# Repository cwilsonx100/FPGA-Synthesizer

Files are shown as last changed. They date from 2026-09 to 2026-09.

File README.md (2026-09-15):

<h3 align="center">FPGA Synthesizer</h3>

  <p align="center">
    A musical synthesizer that runs on an Artix-7 Cmod A7-35T
    <br />
    <br />

  </p>
</div>

## Overview

Includes 10-Voice Polyphony with Filters, Detune Oscillators, Phase Modulation, and ADSR. All with Variable controls.

Includes a Mono Sequencer with in-key randomization options.

Waveforms and Timing decisions are generated on the FPGA, while the User Interface and Variable controls are delegated to the PI.

A Modular System that supports up to 64 Potentiometers for Variable controls.

Connects to any MIDI keyboard through a standard MIDI DIN cable.

### Built With

* [][Verilog-url]
* [][Kicad-url]
* [][Vivado-url]
* [][Python-url]
* [][MIDI-url]
* [][pi-url]
* [][FastAPI-url]

### Main Hardware

Artix-7 Cmod A7-35T

Adafruit I2S Stereo Decoder - UDA1334A Breakout

Raspberry Pi 4 Model B

Full Hardware list is in the BOM

## Functional overview

### Artix-7 Cmod A7-35T FPGA

The FPGA generates the base waveforms and timing sequences through MMCM.

More complex waveforms use wavetables with a saw wave as their reference.

Note and MIDI Values are stored as LUTs.

Filters and effects then alter the waveform with predictable algorithms and formulas.

The FPGA then parses MIDI data to send the waveform to a DAC.

### Raspberry Pi 4 Model B

The Pi handles everything on the User end.

The User Interface allows for a modular system of up to 64 potentiometers, but also allows for a fully digital system with no analog components.

Allows for a fully customizable sequencer system with in-key randomizers and timing variables.

Communicates variable changes and timing to the FPGA through SPI.

### PCB

Includes Gerber Files and a full BOM.

The prototype was first breadboarded and then designed in KiCad.

Schematic

PCB

3dBoard

<!-- CONTACT -->
## Contact

Connor Wilson - Cwilsonx100@gmail.com

<!-- MARKDOWN LINKS & IMAGES -->
[Verilog.com]: https://img.shields.io/badge/Hardware-Verilog-blue
[Verilog-url]: https://www.verilog.com/
[Kicad.org]: https://img.shields.io/badge/Hardware-KiCad-blue
[Kicad-url]: https://www.kicad.org/
[AMD.com]: https://img.shields.io/badge/EDA-Vivado-blue
[Vivado-url]: https://www.amd.com/en/products/software/adaptive-socs-and-fpgas/vivado.html
[Python.org]: https://img.shields.io/badge/Python-3776AB?logo=python&logoColor=fff
[Python-url]: https://www.python.org/
[MIDI.org]: https://img.shields.io/badge/-MIDI-000000?style=for-the-badge&logo=midi&logoColor=white
[MIDI-url]: https://midi.org/
[raspberrypi.com]: https://img.shields.io/badge/-RaspberryPi-C51A4A?style=for-the-badge&logo=Raspberry-Pi
[PI-url]: https://www.raspberrypi.com/
[fastapi.tiangolo.com]: https://img.shields.io/badge/FastAPI-005571?style=for-the-badge&logo=fastapi
[FastAPI-url]: https://fastapi.tiangolo.com/

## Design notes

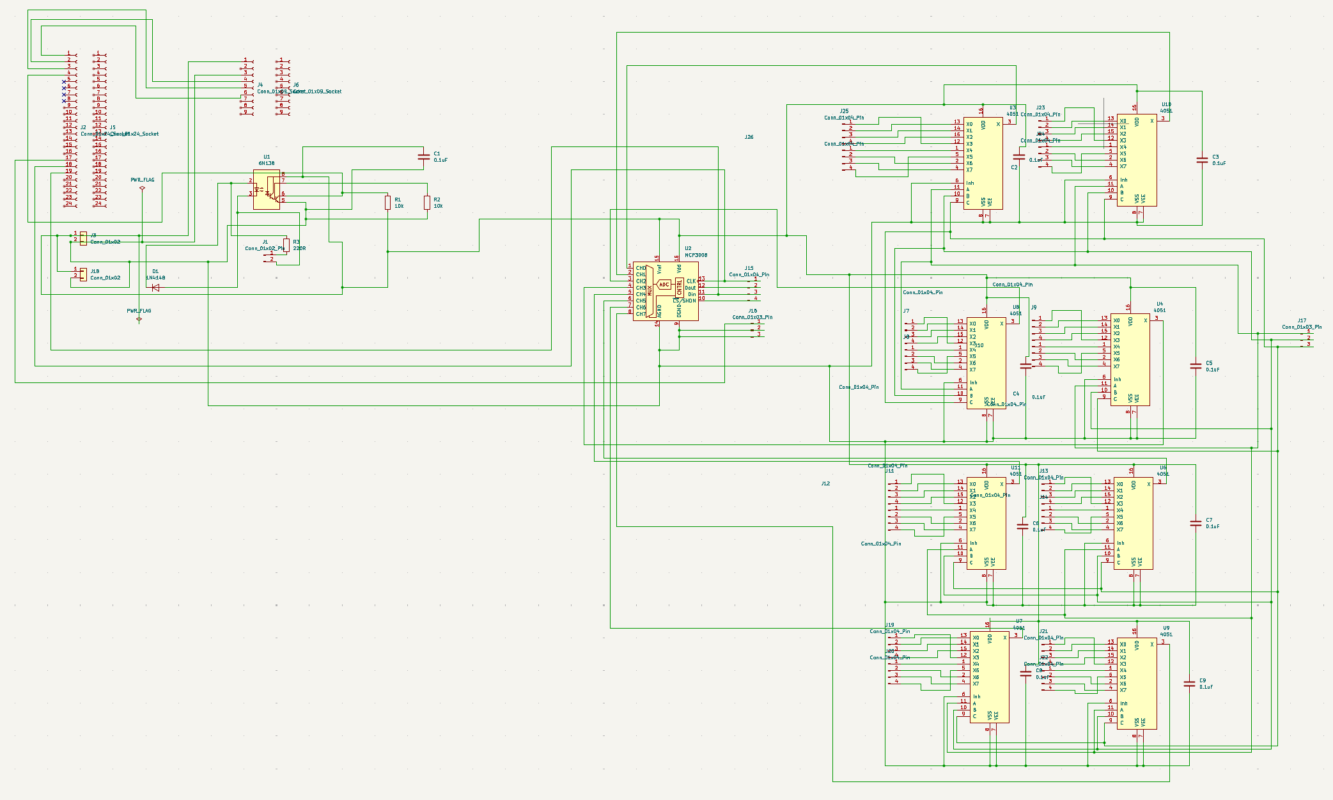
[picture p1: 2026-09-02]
Images/Schematic.png

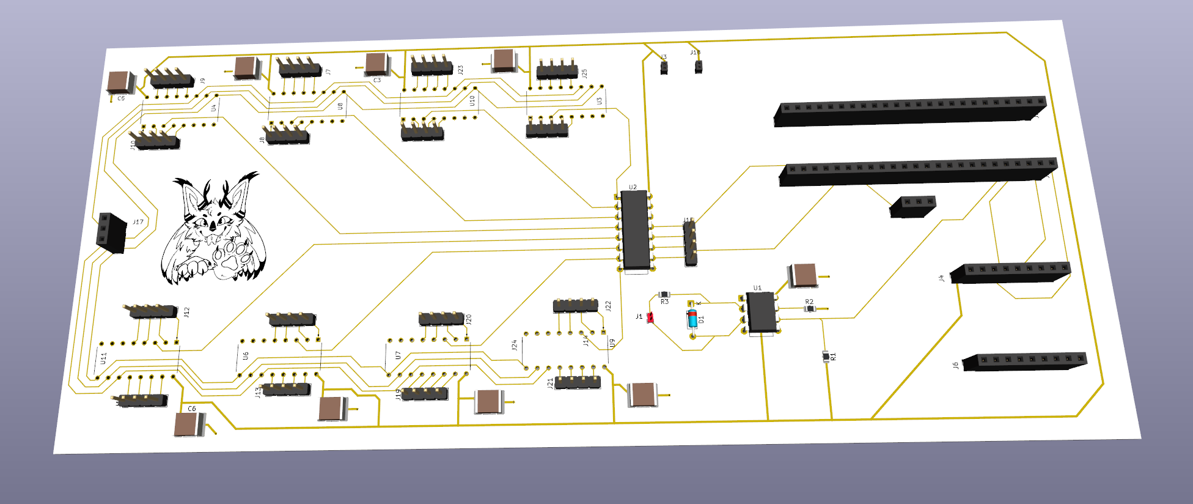
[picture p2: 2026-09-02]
Images/3dBoard.png

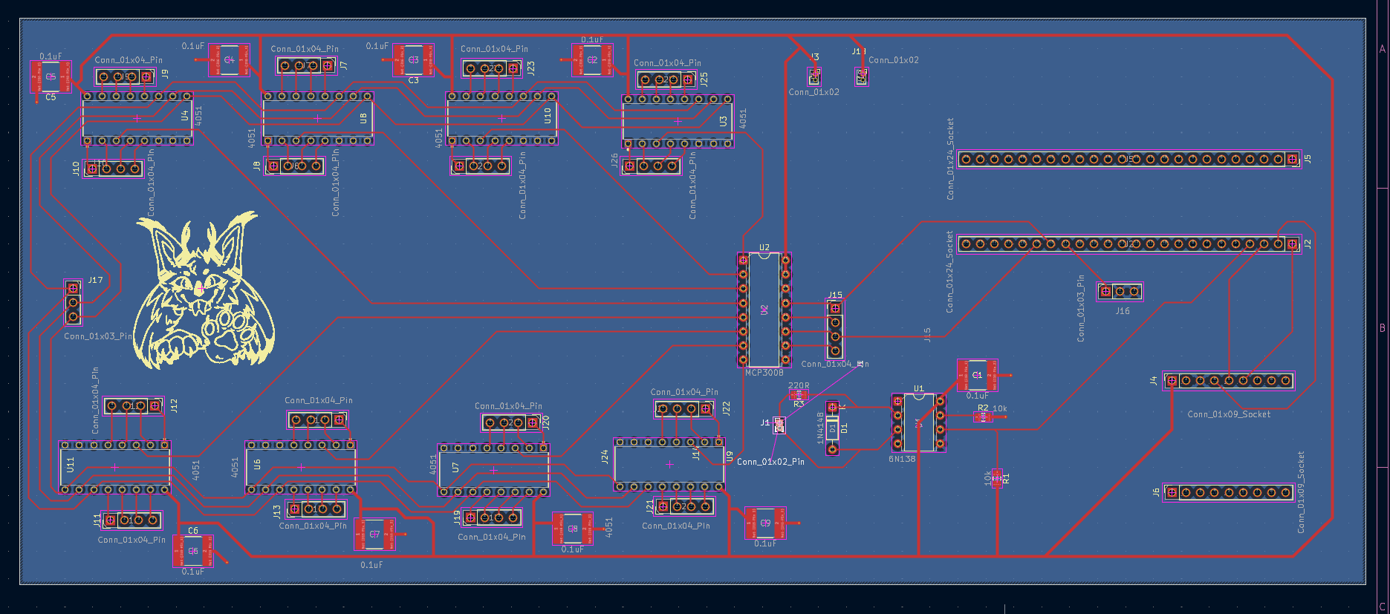
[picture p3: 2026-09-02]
Images/PCB.png

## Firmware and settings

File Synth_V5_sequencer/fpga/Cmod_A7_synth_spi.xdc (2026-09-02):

## Cmod A7 configuration voltage settings
set_property CFGBVS VCCO [current_design]
set_property CONFIG_VOLTAGE 3.3 [current_design]

## 12 MHz board clock (onboard oscillator)
set_property -dict { PACKAGE_PIN L17 IOSTANDARD LVCMOS33 } [get_ports { clk }]
## NOTE: do NOT add create_clock here. The clk_wiz_0 IP already constrains the
## 12 MHz input clock (its in-context XDC). A second create_clock on this pin
## causes CRITICAL WARNING [Constraints 18-1056] "completely overrides clock",
## which corrupts audio-clock timing and makes the SPI slave unreliable.

## Onboard LED
set_property -dict { PACKAGE_PIN A17 IOSTANDARD LVCMOS33 } [get_ports { led0 }]

## I2S to UDA1334A  (DIP pins 1/2/3 = pio1/2/3)
set_property -dict { PACKAGE_PIN M3  IOSTANDARD LVCMOS33 } [get_ports { i2s_bclk }]
set_property -dict { PACKAGE_PIN L3  IOSTANDARD LVCMOS33 } [get_ports { i2s_lrclk }]
set_property -dict { PACKAGE_PIN A16 IOSTANDARD LVCMOS33 } [get_ports { i2s_sdin }]

## MIDI input  (DIP pin 4 = pio4, notes only)
set_property -dict { PACKAGE_PIN K3  IOSTANDARD LVCMOS33 } [get_ports { midi_rx }]

## ======================================================================
## SPI from Raspberry Pi (Pi = master, FPGA = slave)
## Placed on the high-numbered header pins, clear of audio/MIDI (pins 1-4)
## and the analog pins (15/16). Package pins verified against Digilent's
## Cmod A7 Master XDC (DIP pin N == pio[N]).
##
##   Signal     DIP pin (silkscreen)   pio     Package pin
##   spi_cs_n         17               pio17       M1
##   spi_sclk        18               pio18       N3
##   spi_mosi        19               pio19       P3
## ======================================================================
set_property -dict { PACKAGE_PIN M1  IOSTANDARD LVCMOS33 } [get_ports { spi_cs_n }]
set_property -dict { PACKAGE_PIN N3  IOSTANDARD LVCMOS33 } [get_ports { spi_sclk }]
set_property -dict { PACKAGE_PIN P3  IOSTANDARD LVCMOS33 } [get_ports { spi_mosi }]

## SPI is slow/async relative to clk_audio; synchronizers handle crossing.
## Mark the SPI inputs as false paths to avoid meaningless timing errors.
set_false_path -from [get_ports { spi_sclk spi_mosi spi_cs_n }]

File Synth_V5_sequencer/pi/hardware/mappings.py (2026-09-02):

"""
Register map, muxed-pot layout, and scaling. Single source of truth shared
conceptually with the FPGA Param_regfile.v.

Hardware: the PCB has 8x CD74HC4051 mux positions, one per MCP3008 channel,
all sharing select lines (index 0..7). Populate as few or as many as you like:
set ENABLED_MUX_CHANNELS to just the ADC channels whose mux is actually
soldered down. Unpopulated channels are skipped entirely, which also keeps the
scan fast.

A pot is addressed by (adc_channel, mux_index):

    slot = adc_channel * 8 + mux_index      (0..63)

PCB mux -> ADC channel map (from the KiCad netlist):
    U3 -> CH0    U10 -> CH1   U8  -> CH2   U4 -> CH3
    U11-> CH4    U6  -> CH5   U7  -> CH6   U9 -> CH7
"""
import math

FS = 48000  # audio sample rate (must match FPGA)

# ---- register addresses (must match Param_regfile.v) ----
REG = {
    "attack":        0x00,
    "decay":         0x01,
    "sustain":       0x02,
    "release":       0x03,
    "pulse_width":   0x04,
    "detune":        0x05,
    "filter_f":      0x06,
    "volume":        0x07,
    "waveform":      0x08,
    "voice_mask":    0x09,
    "mute":          0x0A,
    "filter_bypass": 0x0B,
    "osc_b":         0x0C,
    "filter_q":      0x0D,
    "filter_type":   0x0E,
}

# ---- WHICH MUXES ARE POPULATED -------------------------------------------
# The board has all 8 positions; list only the ADC channels you actually
# populated. Add a channel here when you solder that mux down - nothing else
# needs to change. Example: [0] for one mux, [0,1,2] for three, range(8) for all.
ENABLED_MUX_CHANNELS = list(range(8))

# PCB reference designator per ADC channel (for the GUI / documentation only)
MUX_REFDES = {0: "U3", 1: "U10", 2: "U8", 3: "U4",
              4: "U11", 5: "U6", 6: "U7", 7: "U9"}

MUX_ADC_CHANNELS = list(ENABLED_MUX_CHANNELS)   # scanned channels
MUX_COUNT = len(MUX_ADC_CHANNELS)
POT_COUNT = MUX_COUNT * 8
MAX_POT_COUNT = 64                              # if all 8 muxes populated


def slot_to_addr(adc_channel, mux_index):
    return adc_channel * 8 + mux_index


# ---- special scaling for the two filter knobs ----
def cutoff_to_f(v01):
    """Pot 0..1 -> SVF f coefficient (Q14). Log-mapped cutoff 30 Hz..7500 Hz.
       f = sin(pi*Fc/Fs) (calibrated to this filter)."""
    fmin, fmax = 30.0, 7500.0
    fc = fmin * (fmax / fmin) ** v01           # exponential/log sweep
    f_real = math.sin(math.pi * fc / FS)
    f_real = max(0.0, min(0.90, f_real))        # hard cap < 1.0 for SVF stability
    return int(round(f_real * 16384))          # Q14 (<= ~14746, safely < 16384)


def resonance_to_q(v01):
    """Pot 0..1 -> SVF q coefficient (Q14). q = 1/Q.
       Low pot = damped (q~1.4), high pot = very resonant (q small)."""
    qmin_res, qmax_res = 0.05, 1.5             # q_real range (small = resonant)
    # invert so clockwise = more resonance (smaller q)
    q_real = qmax_res + (qmin_res - qmax_res) * v01
    q_real = max(0.02, min(3.99, q_real))
    return int(round(q_real * 16384))          # Q14


def _lin(v01, lo, hi):
    return int(round(lo + (hi - lo) * v01))


# ---- pot slot assignments -------------------------------------------------
# Each entry maps a physical pot slot to a parameter and how to scale it.
# kind: "lin" (linear 16-bit), "int" (small integer), or "special" (callable).
# 'invert' flips pot direction. Slots not listed here are simply unused.
POT_MAP = {
    # ---- Mux A (ADC CH0), pots 0..7 ----
    0:  dict(param="attack",      reg="attack",      kind="lin",  lo=3,    hi=2500),
    1:  dict(param="decay",       reg="decay",       kind="lin",  lo=2,    hi=1500),
    2:  dict(param="sustain",     reg="sustain",     kind="lin",  lo=0,    hi=65535),
    3:  dict(param="release",     reg="release",     kind="lin",  lo=2,    hi=2000),
    4:  dict(param="cutoff",      reg="filter_f",    kind="special", fn="cutoff_to_f"),
    5:  dict(param="resonance",   reg="filter_q",    kind="special", fn="resonance_to_q"),
    6:  dict(param="pulse_width", reg="pulse_width", kind="lin",  lo=3000, hi=62000),
    7:  dict(param="volume",      reg="volume",      kind="lin",  lo=0,    hi=65535),
    # ---- Mux B (ADC CH1), pots 8..15 ----
    8:  dict(param="detune",      reg="detune",      kind="int",  lo=0,    hi=7),
    # 9..15 free for expansion
    # ---- Mux C (ADC CH2), pots 16..23 ----
    # 16..23 free for expansion
}

# ---- toggle / choice params: GUI-controlled, with defaults ----
TOGGLES = {
    "waveform":      dict(default=3, lo=0, hi=9),
    "voice_mask":    dict(default=0b1111111111, lo=0, hi=1023),
    "mute":          dict(default=0, lo=0, hi=1),
    "filter_bypass": dict(default=0, lo=0, hi=1),
    "osc_b":         dict(default=1, lo=0, hi=1),
    "filter_type":   dict(default=0, lo=0, hi=3),   # 0 LP 1 BP 2 HP 3 notch
}

WAVEFORM_NAMES = {0:"Saw",1:"Square",2:"Triangle",3:"Sine",4:"Organ",5:"Growl",6:"Formant",7:"Half Sine",8:"Fold",9:"Bell"}
NUM_VOICES = 10
FILTER_TYPE_NAMES = {0: "Low-pass", 1: "Band-pass", 2: "High-pass", 3: "Notch"}

_SPECIAL = {"cutoff_to_f": cutoff_to_f, "resonance_to_q": resonance_to_q}


def scale_pot(spec, adc_value):
    """Convert a raw 0..1023 ADC reading into a 16-bit register value."""
    v01 = max(0.0, min(1.0, adc_value / 1023.0))
    if spec.get("invert"):
        v01 = 1.0 - v01
    if spec["kind"] == "special":
        return _SPECIAL[spec["fn"]](v01)
    val = _lin(v01, spec["lo"], spec["hi"])
    return max(0, min(65535, val))


def active_pot_map():
    """POT_MAP entries whose ADC channel is actually populated."""
    return {slot: spec for slot, spec in POT_MAP.items()
            if (slot // 8) in ENABLED_MUX_CHANNELS}


def slot_label(slot):
    ch, idx = slot // 8, slot % 8
    return f"{MUX_REFDES.get(ch, '?')} CH{ch}.Y{idx}"


def manual_to_register(spec, slider_value):
    """Convert a MANUAL slider value (0..65535) into the register value.
    For 'special' params (cutoff, resonance) the slider is treated as a
    position and run through the same mapping the pot uses, so manual and
    pot behave identically and both stay in the filter's stable range.
    For ordinary params the slider value is used directly (already a
    register value)."""
    if spec["kind"] == "special":
        v01 = max(0.0, min(1.0, slider_value / 65535.0))
        return _SPECIAL[spec["fn"]](v01)
    return max(0, min(65535, int(slider_value)))


# ---- sequencer registers (V5) ----
SEQ_REG = {
    "run_length":   0x20,   # bit0=run, bits[4:1]=length
    "step_period":  0x21,
    "gate_length":  0x22,
    "s_attack":     0x30, "s_decay": 0x31, "s_sustain": 0x32, "s_release": 0x33,
    "s_pulse_width":0x34, "s_detune": 0x35, "s_filter_f": 0x36, "s_volume": 0x37,
    "s_waveform":   0x38, "s_mute": 0x3A, "s_filter_bypass": 0x3B, "s_osc_b": 0x3C,
    "s_filter_q":   0x3D, "s_filter_type": 0x3E,
}
SEQ_STEP_BASE = 0x10   # step i -> 0x10+i

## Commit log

2026-09-02 Gerber Files
    [TestProj1-B_Cu.gbr, TestProj1-B_Mask.gbr, TestProj1-B_Paste.gbr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]
2026-11-06 Remove schematic image from README
    Removed schematic image from README.
